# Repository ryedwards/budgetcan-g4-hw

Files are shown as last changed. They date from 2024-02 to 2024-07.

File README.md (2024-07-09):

# BudgetCAN G4

Hardware files for a simple CAN and LIN device built around an STM32 G4 MCU

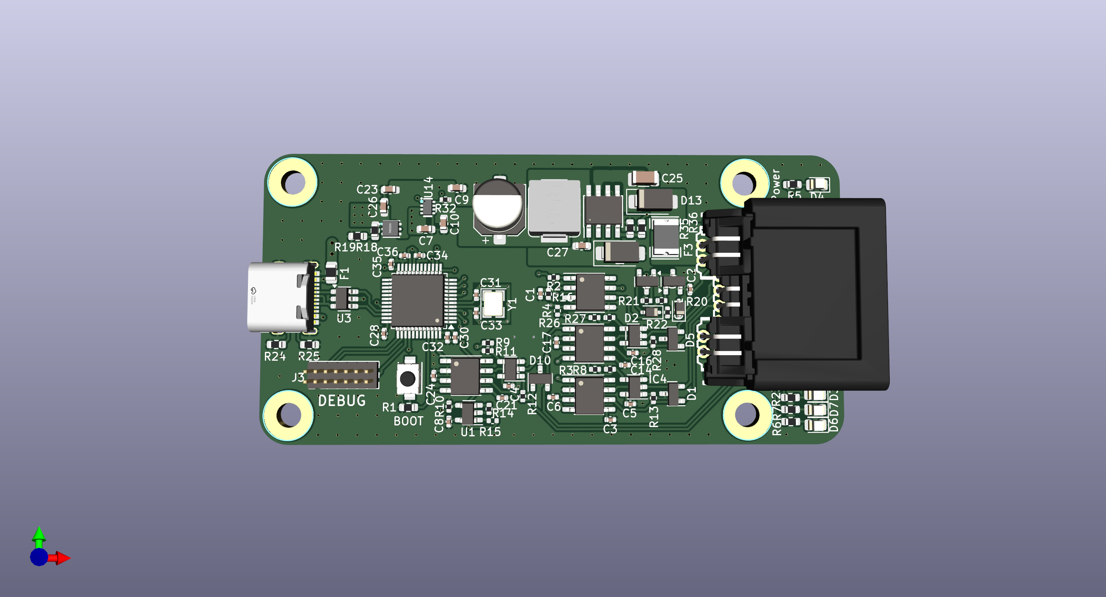
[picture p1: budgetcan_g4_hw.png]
budgetcan_g4_hardware


## Description

The BudgetCAN G4 Hardware is designed to implement the full CAN potential of the STM32G4 MCU.  The hardware has been designed with the following features:
* USB-C connector for robust connectivity to a host machine
* 3 CANFD channels each with SW selectable termination resistors
* 1 LIN channel with SW selectable master pull-up
* 12V power input provides power for LIN and a 3A 5V regulator
* Debug header pinout for STLINK v3 Mini 14-pin connector - the VCP pins are routed to a UART for debugging
* Onboard 8Mhz crystal provides high clock accuracy for CANFD
* 5V power MUX to ensure graceful handoff between USB and 12V power supplies
* 3x configurable LEDs for status indications
* Automotive grade Molex Mini50 connector
* 4 layer PCB
* BOM cost under $15USD

## File usage

* The HW was designed with KiCad8
* Part BOM included with the schematic is complete for JLCPCB parts

## Firmware
Firmware is available for this hardware in the budgetcan firmware repository.  This firmware is based on the gs_usb driver and currently is fully supported in Linux and will work in Windows using the same drivers that have been developed for gs_usb.
* https://github.com/ryedwards/budgetcan-fw

You can also use the included STM32CubeMX .ioc file to generate your own firmware.  

This hardware can also be used as a standalone device (gateway module, simulated ECU, etc) since it has a 12V input and can be used headless.

## Help

If you find any issues with the hardware please submit an issue into GitHub

## License

This project is licensed under the MIT License - see the LICENSE.md file for details

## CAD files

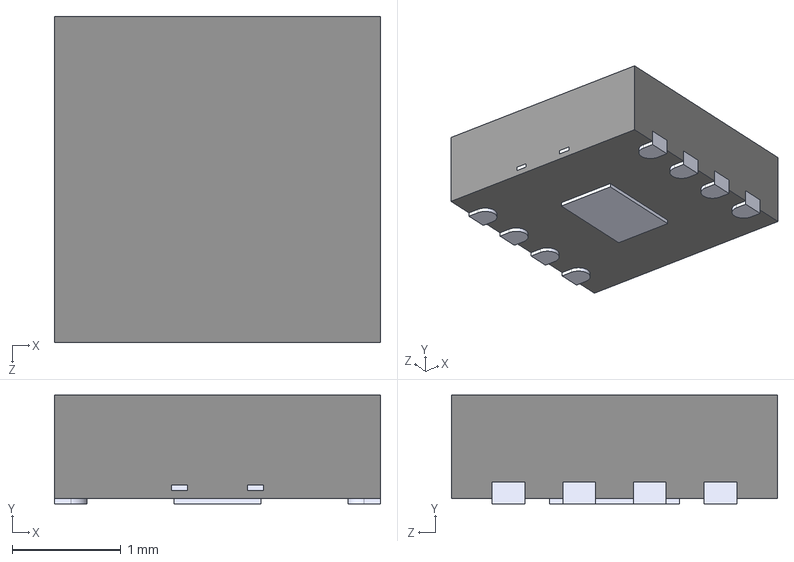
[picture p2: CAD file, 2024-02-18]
3dmodels/MF-TJA1021TK.STEP
3.00 x 1.00 x 3.00 mm

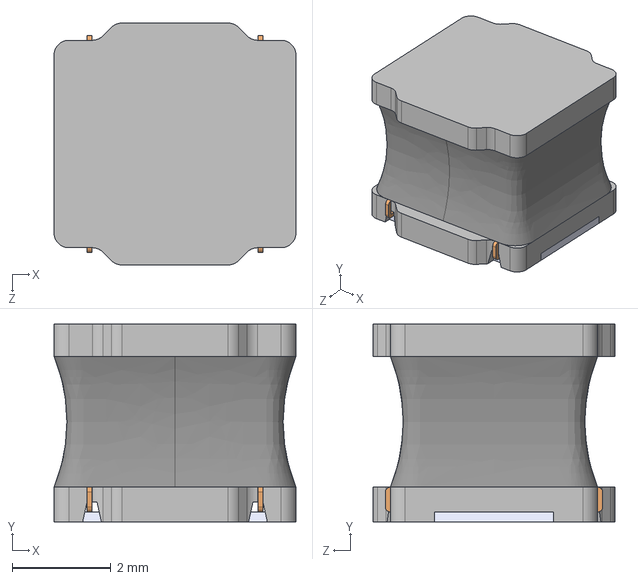
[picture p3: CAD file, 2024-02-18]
3dmodels/LQH5BPN3R3N38L.STEP
4.90 x 4.00 x 4.90 mm

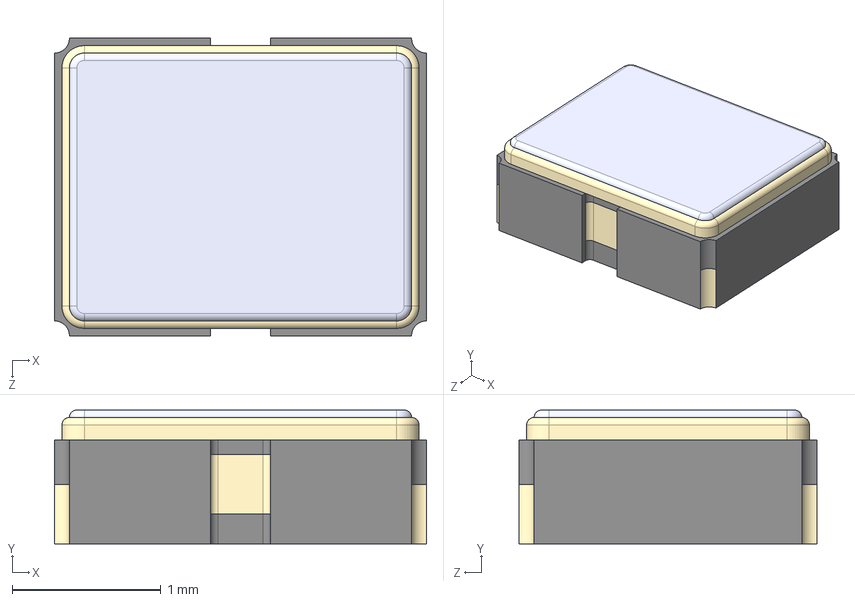
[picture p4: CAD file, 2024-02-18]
3dmodels/ECS-2520MVLC-080-BN-TR.STEP
2.50 x 0.9 x 2.00 mm

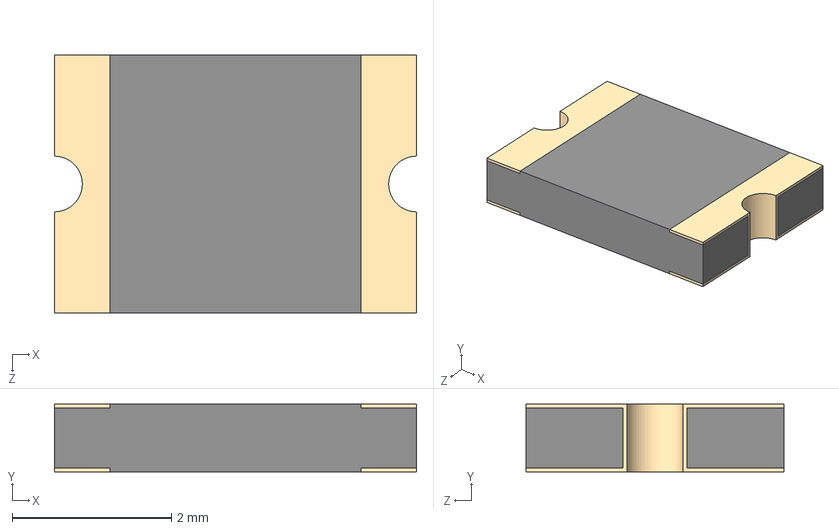
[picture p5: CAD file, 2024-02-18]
3dmodels/MF-MSMF050.STEP
4.55 x 0.85 x 3.24 mm

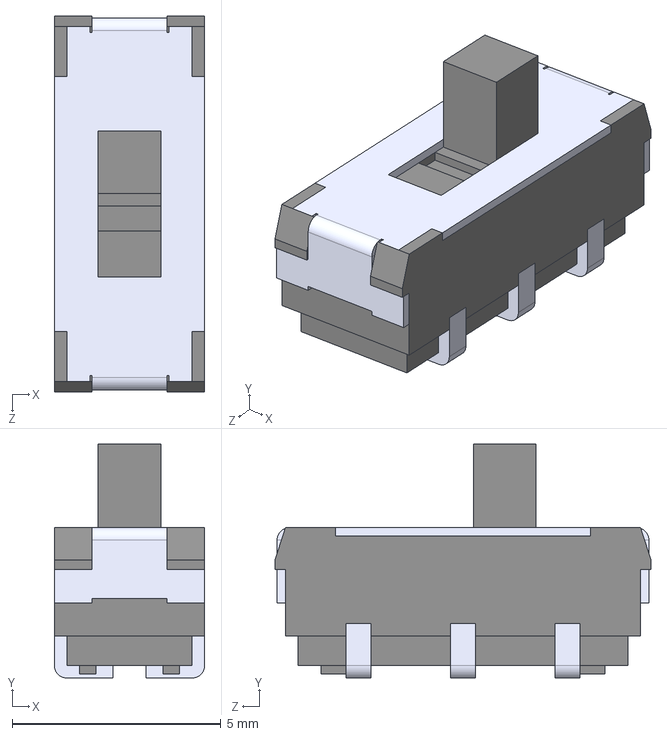
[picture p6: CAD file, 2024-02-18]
3dmodels/JS202011JCQN.STEP
3.60 x 5.60 x 9.00 mm

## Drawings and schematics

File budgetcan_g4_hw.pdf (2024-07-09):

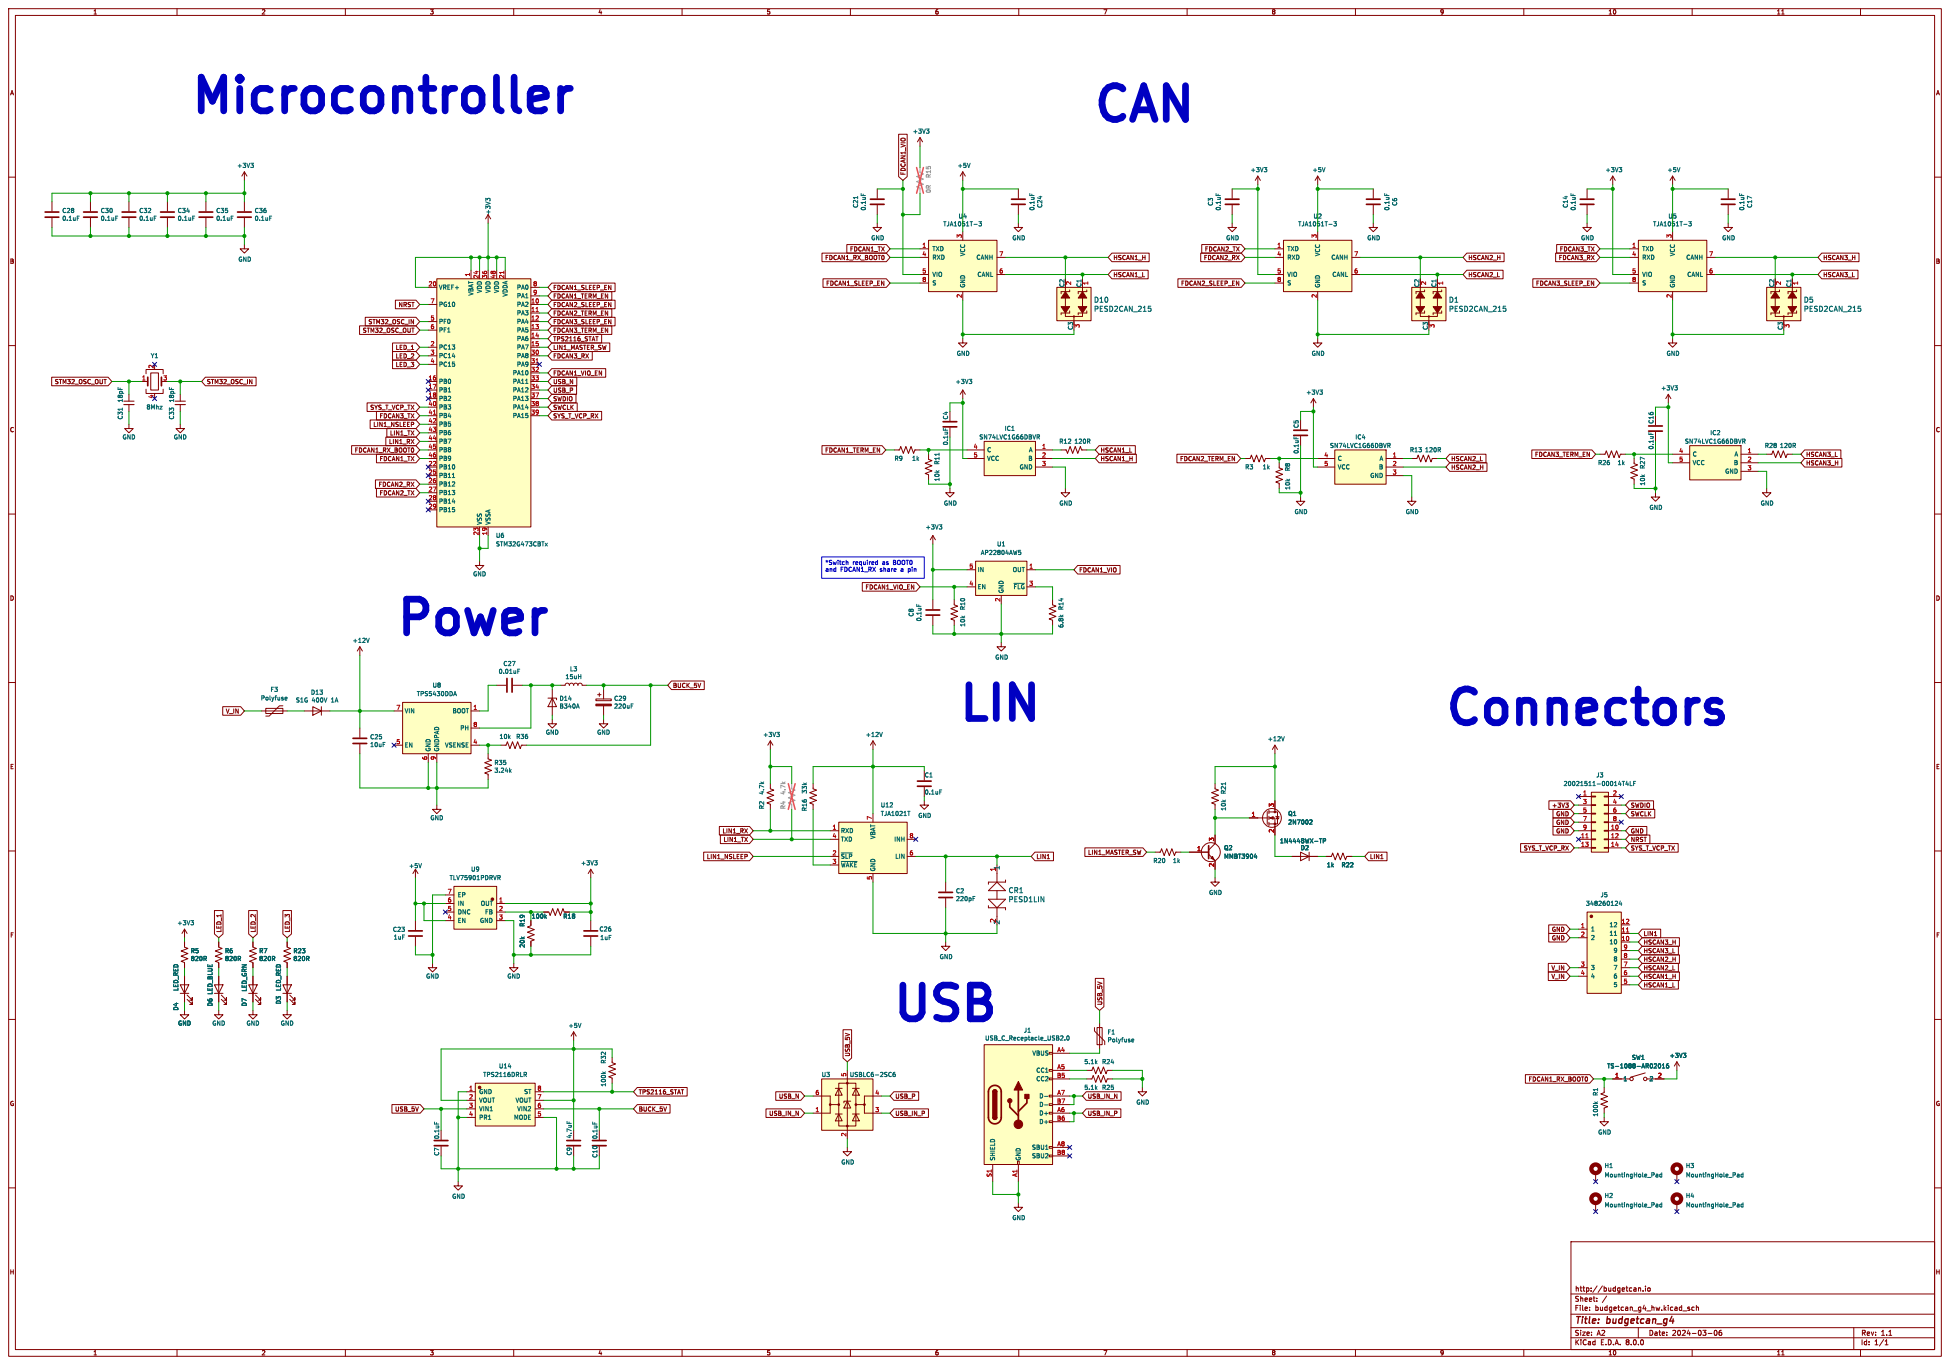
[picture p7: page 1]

3 RXD 4 VIO 5 CANL 6 CANH 7 S

1 PA2 10 PA3 11 PA4 12 PA5 13 PA6 14 PA7 15 PB0 16 PB1 17 PB2 18 VSSA 19 PC13 2 VREF+ 20 VDDA 21 PB10 22 VSS 23 VDD 24 PB11 25 PB12 26 PB13 27 PB14 28 PB15 29 PC14 3 PA8 30 PA9 31 PA10 32 PA11 33 PA12 34 VDD 36 PA13 37 PA14 38 PA15 39 PC15 4 PB3 40 PB4 41 PB5 42 PB6 43 PB7 44 PB8 45 PB9 46 VDD 48 PF0 5 PF1 6 PG10 7 PA0 8 PA1 9 U6STM32G473CBTx C10 0.1uF

File: budgetcan_g4_hw.kicad_sch Sheet: / http://budgetcan.io R10 10k

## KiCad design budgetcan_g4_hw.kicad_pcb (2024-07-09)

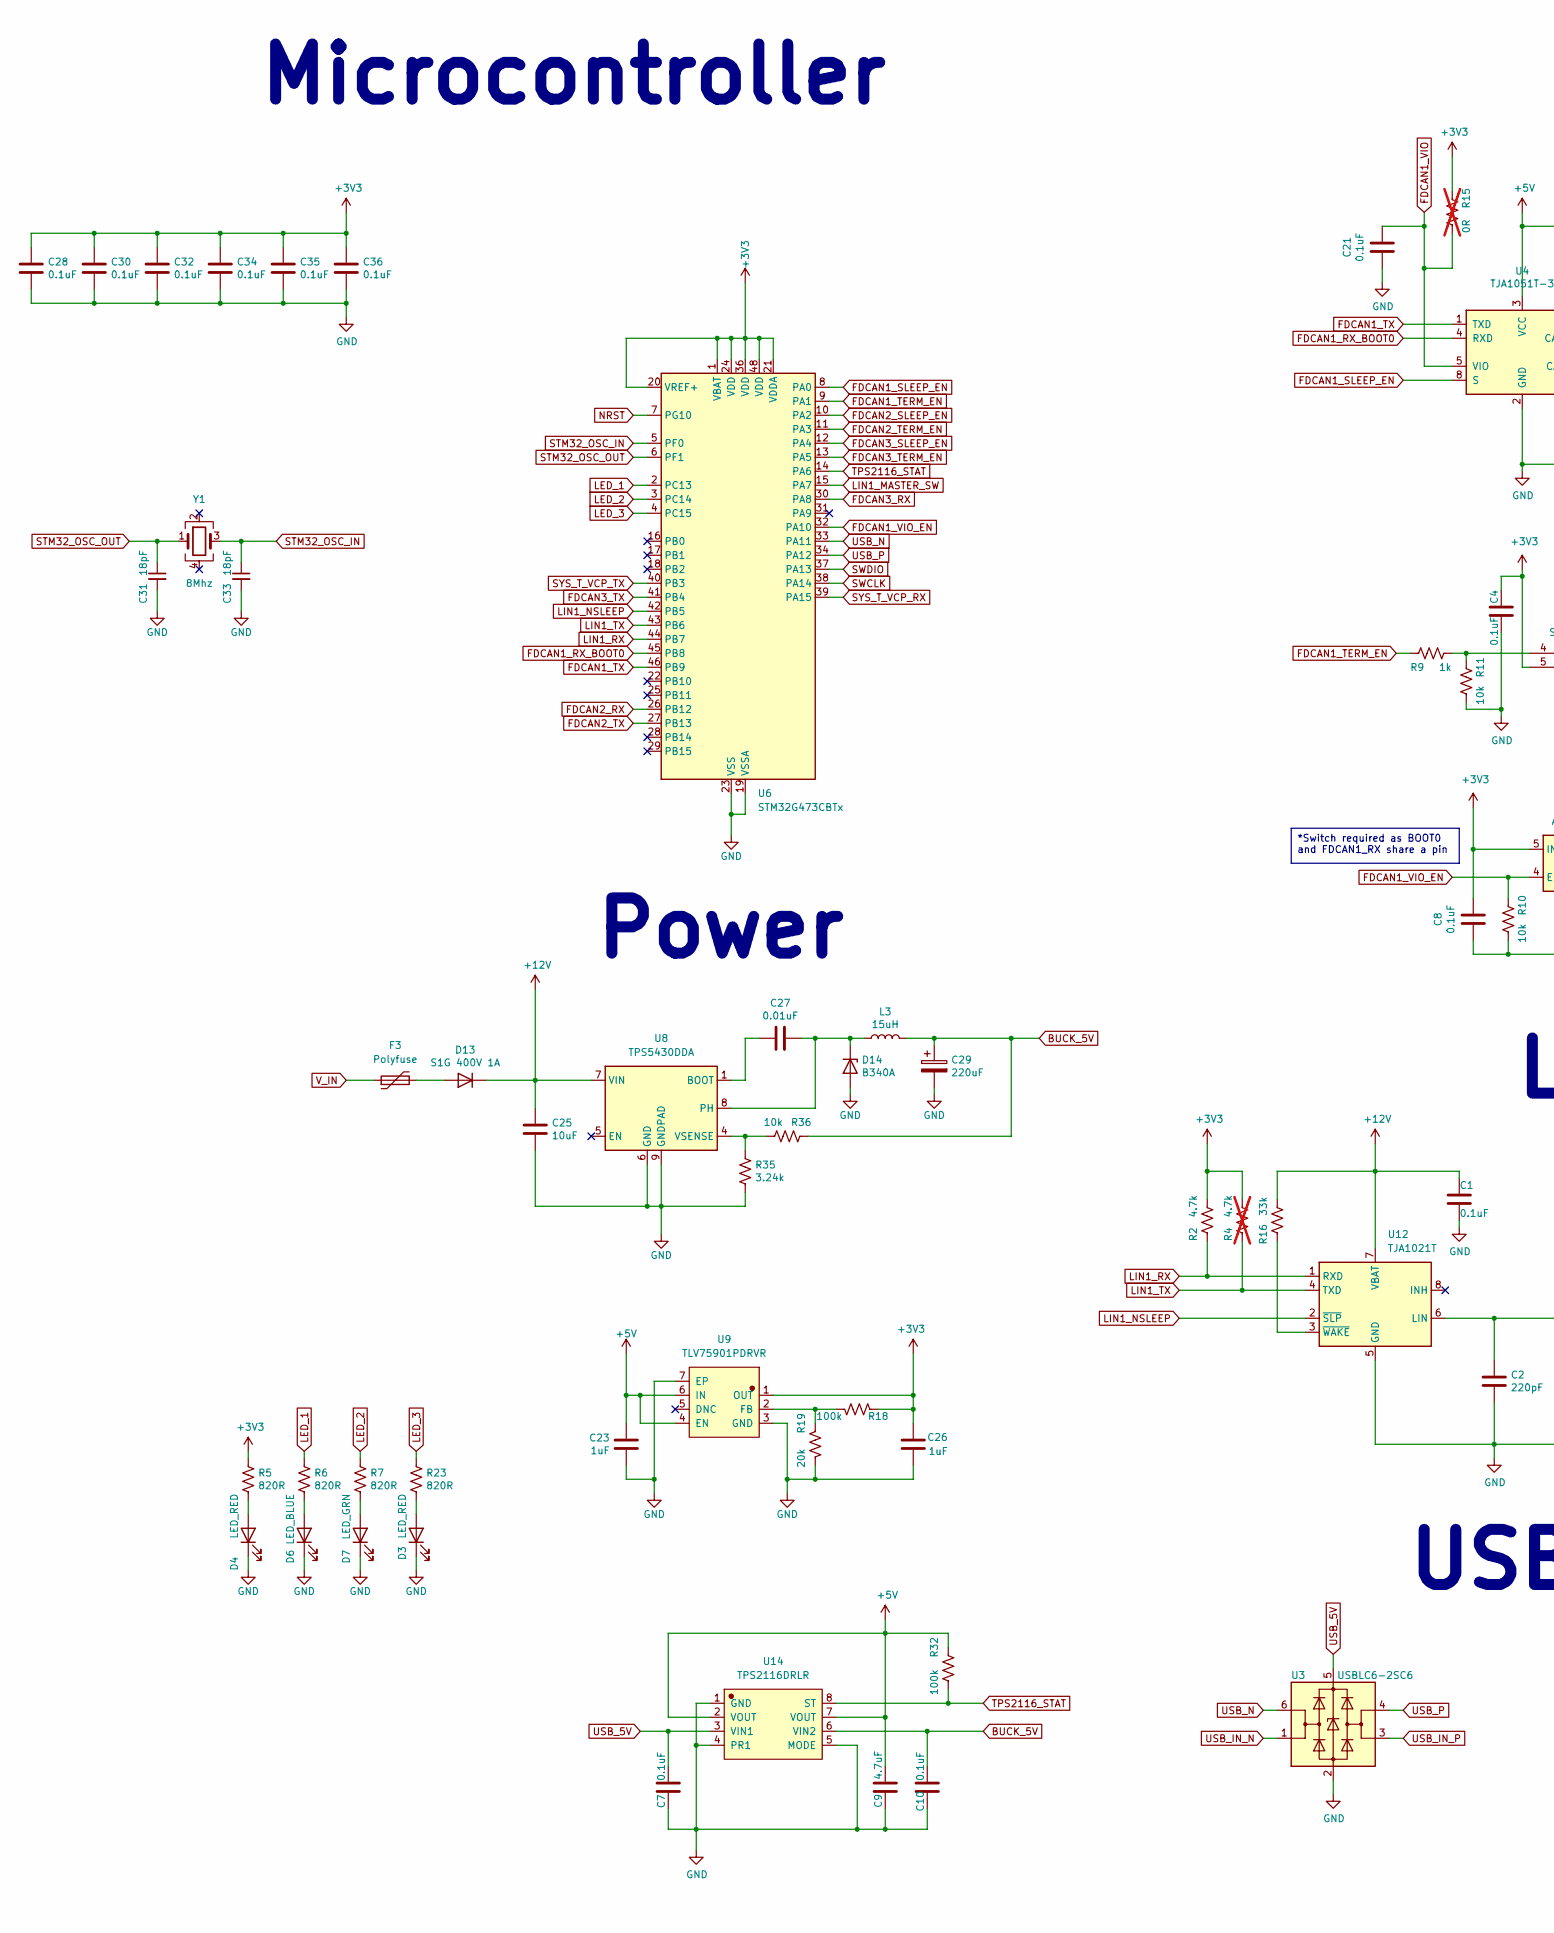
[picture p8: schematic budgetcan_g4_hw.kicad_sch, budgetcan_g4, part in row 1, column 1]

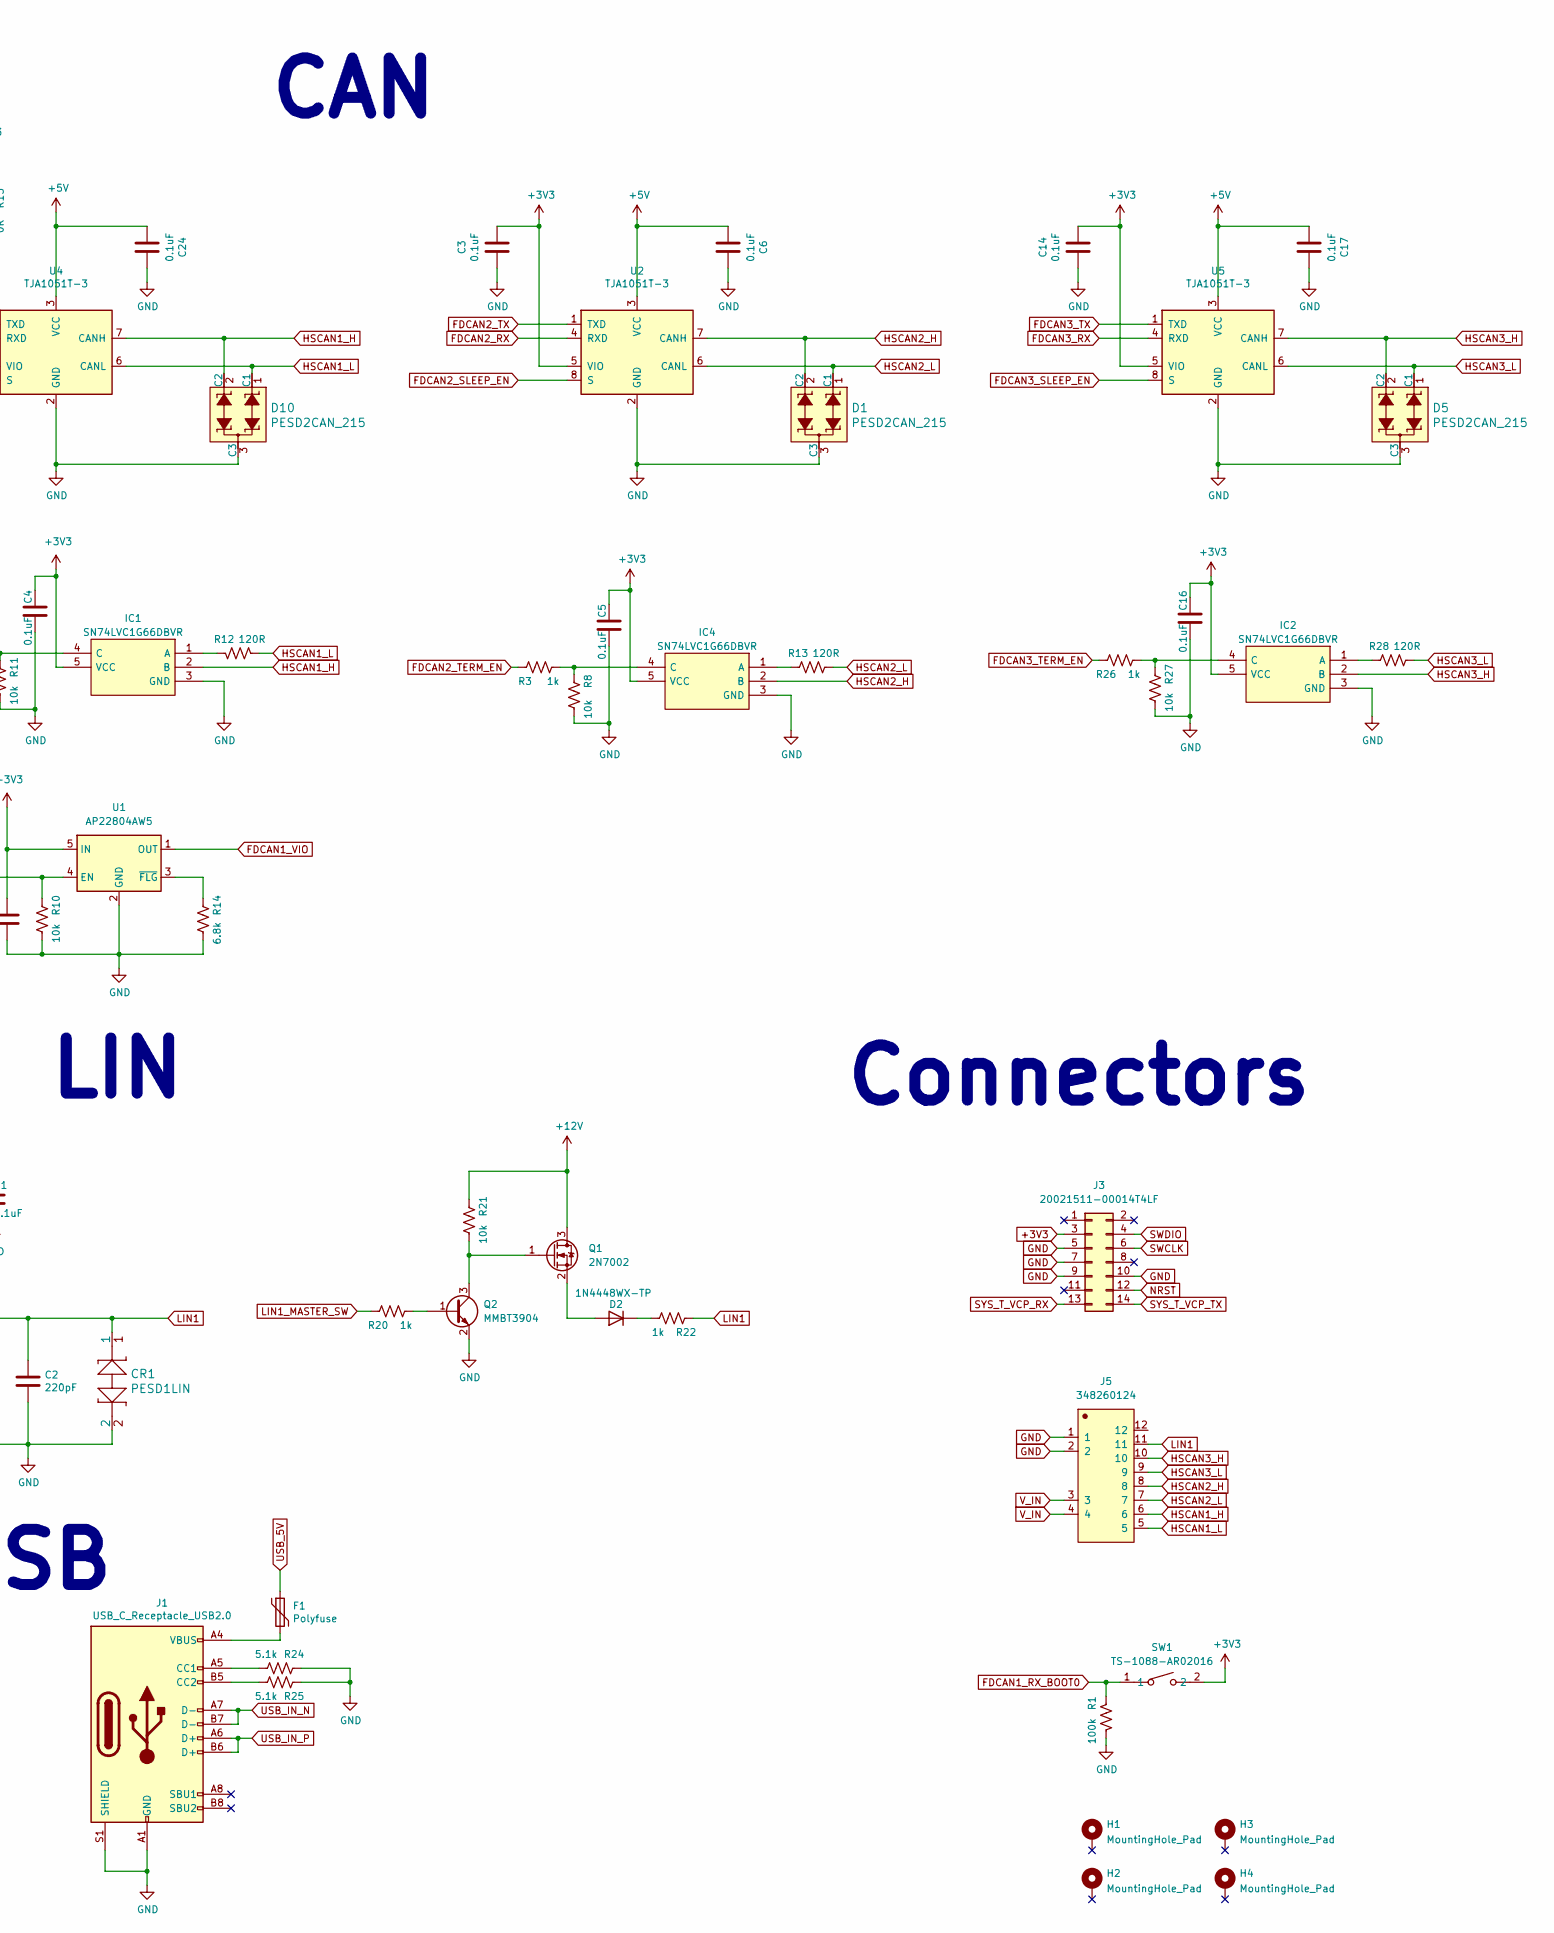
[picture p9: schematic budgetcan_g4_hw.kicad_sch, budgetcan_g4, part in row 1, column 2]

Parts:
C1, C3, C4, C5, C6, C8, C14, C16, C17, C21, C24: 0.1uF; C_0402_1005Metric; Manufacturer_Part_Number CC0603KRX7R8BB104; LCSC Part # C1525
C2: 220pF; C_0402_1005Metric; Manufacturer_Part_Number CC0603JRNPO9BN221; LCSC Part # C1530
C7, C10: 0.1uF; C_0603_1608Metric; Manufacturer_Part_Number CC0603KRX7R8BB104; LCSC Part # C14663
C9: 4.7uF; C_0603_1608Metric; LCSC Part # C19666
C23, C26: 1uF; C_0603_1608Metric; LCSC Part # C15849
C25: 10uF; C_1206_3216Metric; Manufacturer_Part_Number CL31B106KQHNFNE; LCSC Part # C13585
C27: 0.01uF; C_0603_1608Metric; LCSC Part # C57112
C28, C30, C32, C34, C35, C36: 0.1uF; C_0402_1005Metric; LCSC Part # C1525
C29: 220uF; CP_Elec_6.3x5.4; LCSC Part # C88676
C31, C33: 18pF; C_0402_1005Metric; LCSC Part # C1549
CR1: PESD1LIN; D_SOD-323; Manufacturer_Part_Number PESD1LIN,135; LCSC Part # C2831530
D1, D5, D10: PESD2CAN_215; SOT-23; MPN PESD2CAN,215; Digi-Key_PN 1727-3891-1-ND
D2: ‎1N4448WX-TP‎; D_SOD-323; Manufacturer_Part_Number ‎1N4448WX-TP‎; Digi-Key_PN 1N4448WXTPMSCT-ND
D3, D4: LED_RED; LED_0805_2012Metric; LCSC Part # C84256
D6: LED_BLUE; LED_0805_2012Metric; LCSC Part # C965817
D7: LED_GRN; LED_0805_2012Metric; LCSC Part # C2297
D13: S1G 400V 1A; D_SMA; Manufacturer_Part_Number S1G; LCSC Part # C95872
D14: B340A; D_SMA; LCSC Part # C3018525
F1: Polyfuse; Fuse_0805_2012Metric; Manufacturer_Part_Number 0ZCK0035FF2G; LCSC Part # C2833485
F3: Polyfuse; F1812; Manufacturer_Part_Number 0ZCG0200AF2B; Digi-Key_PN 507-2074-1-ND
H1, H2, H3, H4: MountingHole_Pad; MountingHole_3.2mm_M3_Pad_TopBottom
IC1, IC2, IC4: SN74LVC1G66DBVR; SOT-23-5; Manufacturer_Part_Number SN74LVC1G66DBVR; LCSC Part # C5375974
J1: USB_C_Receptacle_USB2.0; USB_C_Receptacle_Palconn_UTC16-G; Manufacturer_Part_Number USB4085-GF-A; Digi-Key_PN 2073-USB4085-GF-ACT-ND
J3: 20021511-00014T4LF; PinHeader_2x07_P1.27mm_Vertical; Mouser Part Number 200-FTSH10701LDK
J5: 348260124; CONN-TH_348260124; LCSC Part # C587298
L3: 15uH; L_Bourns_SRP7028A_7.3x6.6mm; LCSC Part # C5189959
Q1: 2N7002; SOT-23; LCSC Part # C8545
Q2: MMBT3904; SOT-23; LCSC Part # C20526
R1: 100k; R_0603_1608Metric; Manufacturer_Part_Number RC0603FR-07100KL; LCSC Part # C25803
R2: 4.7k; R_0402_1005Metric; Manufacturer_Part_Number RC0603JR-074K7L; LCSC Part # C25900
R3, R9, R20, R22, R26: 1k; R_0402_1005Metric; Manufacturer_Part_Number RC0603FR-071KL; LCSC Part # C11702
R4: 4.7k; R_0402_1005Metric; LCSC Part # C25900; not fitted
R5, R6, R7, R23: 820R; R_0603_1608Metric; Manufacturer_Part_Number RC0603FR-071KL; LCSC Part # C23253
R8, R10, R11, R21, R27: 10k; R_0402_1005Metric; Manufacturer_Part_Number RC0603FR-0710KL; LCSC Part # C25744
R12, R13, R28: 120R; R_0402_1005Metric; Manufacturer_Part_Number RC0603FR-07120RL; LCSC Part # C25079
R14: 6.8k; R_0402_1005Metric; Manufacturer_Part_Number RC0603FR-0710KL; LCSC Part # C25917
R15: 0R; R_0402_1005Metric; LCSC Part # C17168; not fitted
R16: 33k; R_0402_1005Metric; Manufacturer_Part_Number RC0603FR-0733K2L; LCSC Part # C25779
R18: 100k; R_0603_1608Metric; Manufacturer_Part_Number RC0603FR-0710KL; LCSC Part # C25803
R19: 20k; R_0603_1608Metric; Manufacturer_Part_Number RC0603FR-0710KL; LCSC Part # C4184
R24, R25: 5.1k; R_0603_1608Metric; Manufacturer_Part_Number RC0603JR-075K1L; LCSC Part # C23186
R32: 100k; R_0402_1005Metric; Manufacturer_Part_Number RC0603FR-0710KL; LCSC Part # C25741
R35: 3.24k; R_0603_1608Metric; LCSC Part # C22994
R36: 10k; R_0603_1608Metric; LCSC Part # C25804
SW1: TS-1088-AR02016; SW-SMD_L3.9-W3.0-P4.45; LCSC Part # C720477
U1: AP22804AW5; SOT-23-5; LCSC Part # C89855
U2, U4, U5: TJA1051T-3; SOIC-8_3.9x4.9mm_P1.27mm; LCSC Part # C38695
U3: USBLC6-2SC6; SOT-23-6; Manufacturer_Part_Number USBLC6-2SC6; LCSC Part # C2687116
U6: STM32G473CBTx; LQFP-48_7x7mm_P0.5mm; LCSC Part # C730111
U8: TPS5430DDA; TI_SO-PowerPAD-8_ThermalVias; LCSC Part # C9864
U9: TLV75901PDRVR; WSON-6_L2.0-W2.0-P0.65-TL-EP; LCSC Part # C544759
U12: TJA1021T; SOIC-8_3.9x4.9mm_P1.27mm; LCSC Part # C128810
U14: TPS2116DRLR; SOT-583-8_L2.1-W1.6-P0.50-LS1.6-BL; LCSC Part # C3235557
Y1: 8Mhz; Crystal_SMD_3225-4Pin_3.2x2.5mm; LCSC Part # C963531

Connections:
+3V3: C3.1, C4.1, C5.1, C8.1, C14.1, C16.1, C26.1, C28.1, C30.1, C32.1, C34.1, C35.1, C36.1, IC1.5 (VCC), IC2.5 (VCC), IC4.5 (VCC), J3.3, R2.2, R4.2, R5.2, R15.1, R18.1, SW1.2, U1.5 (IN), U2.5 (VIO), U5.5 (VIO), U6.1 (VBAT), U6.20 (VREF+), U6.21 (VDDA), U6.24 (VDD), U6.36 (VDD), U6.48 (VDD), U9.1 (OUT)
+5V: C6.2, C9.1, C17.2, C23.1, C24.2, R32.1, U2.3 (VCC), U4.3 (VCC), U5.3 (VCC), U9.4 (EN), U9.6 (IN), U14.2 (VOUT), U14.7 (VOUT)
+12V: C1.1, C25.1, D13.1 (K), Q1.3 (D), R16.2, R21.1, U8.7 (VIN), U12.7 (VBAT)
BUCK_5V: C10.1, C29.1, L3.2, R36.2, U14.6 (VIN2)
FDCAN1_RX_BOOT0: R1.1, SW1.1, U4.4 (RXD), U6.45 (PB8)
FDCAN1_SLEEP_EN: U4.8 (S), U6.8 (PA0)
FDCAN1_TERM_EN: R9.1, U6.9 (PA1)
FDCAN1_TX: U4.1 (TXD), U6.46 (PB9)
FDCAN1_VIO: C21.1, R15.2, U1.1 (OUT), U4.5 (VIO)
FDCAN1_VIO_EN: R10.1, U1.4 (EN), U6.32 (PA10)
FDCAN2_RX: U2.4 (RXD), U6.26 (PB12)
FDCAN2_SLEEP_EN: U2.8 (S), U6.10 (PA2)
FDCAN2_TERM_EN: R3.1, U6.11 (PA3)
FDCAN2_TX: U2.1 (TXD), U6.27 (PB13)
FDCAN3_RX: U5.4 (RXD), U6.30 (PA8)
FDCAN3_SLEEP_EN: U5.8 (S), U6.12 (PA4)
FDCAN3_TERM_EN: R26.1, U6.13 (PA5)
FDCAN3_TX: U5.1 (TXD), U6.41 (PB4)
GND: C1.2, C2.2, C3.2, C4.2, C5.2, C6.1, C7.2, C8.2, C9.2, C10.2, C14.2, C16.2, C17.1, C21.2, C23.2, C24.1, C25.2, C26.2, C28.2, C29.2, C30.2, C31.2, C32.2, C33.2, C34.2, C35.2, C36.2, CR1.2, D1.3 (C3), D3.1 (K), D4.1 (K), D5.3 (C3), D6.1 (K), D7.1 (K), D10.3 (C3), D14.2 (A), IC1.3 (GND), IC2.3 (GND), IC4.3 (GND), J1.A1 (GND), J1.A12 (GND), J1.B1 (GND), J1.B12 (GND), J1.S1 (SHIELD), J3.5, J3.7, J3.9, J3.10, J5.1, J5.2, Q2.2 (E), R1.2, R8.2, R10.2, R11.2, R14.2, R19.2, R24.1, R25.1, R27.2, R35.2, U1.2 (GND), U2.2 (GND), U3.2 (GND), U4.2 (GND), U5.2 (GND), U6.19 (VSSA), U6.23 (VSS), U6.35 (VSS), U6.47 (VSS), U8.6 (GND), U8.9 (GNDPAD), U9.3 (GND), U9.7 (EP), U12.5 (GND), U14.1 (GND), U14.4 (PR1), U14.5 (MODE)
HSCAN1_H: D10.2 (C2), IC1.2 (B), J5.6, U4.7 (CANH)
HSCAN1_L: D10.1 (C1), J5.5, R12.2, U4.6 (CANL)
HSCAN2_H: D1.2 (C2), IC4.2 (B), J5.8, U2.7 (CANH)
HSCAN2_L: D1.1 (C1), J5.7, R13.2, U2.6 (CANL)
HSCAN3_H: D5.2 (C2), IC2.2 (B), J5.10, U5.7 (CANH)
HSCAN3_L: D5.1 (C1), J5.9, R28.2, U5.6 (CANL)
LED_1: R6.2, U6.2 (PC13)
LED_2: R7.2, U6.3 (PC14)
LED_3: R23.2, U6.4 (PC15)
LIN1: C2.1, CR1.1, J5.11, R22.1, U12.6 (LIN)
LIN1_MASTER_SW: R20.1, U6.15 (PA7)
LIN1_NSLEEP: U6.42 (PB5), U12.2 (~SLP)
LIN1_RX: R2.1, U6.44 (PB7), U12.1 (RXD)
LIN1_TX: R4.1, U6.43 (PB6), U12.4 (TXD)
NRST: J3.12, U6.7 (PG10)
unnamed: D2.2 (A), Q1.2 (S)
unnamed: D2.1 (K), R22.2
unnamed: D3.2 (A), R23.1
unnamed: D4.2 (A), R5.1
unnamed: D6.2 (A), R6.1
unnamed: D7.2 (A), R7.1
unnamed: D13.2 (A), F3.2
unnamed: C27.1, D14.1 (K), L3.1, U8.8 (PH)
unnamed: F1.2, J1.A4 (VBUS), J1.A9 (VBUS), J1.B4 (VBUS), J1.B9 (VBUS)
unnamed: IC1.1 (A), R12.1
unnamed: IC1.4 (C), R9.2, R11.1
unnamed: IC2.1 (A), R28.1
unnamed: IC2.4 (C), R26.2, R27.1
unnamed: IC4.1 (A), R13.1
unnamed: IC4.4 (C), R3.2, R8.1
unnamed: J1.A5 (CC1), R24.2
unnamed: J1.B5 (CC2), R25.2
unnamed: Q1.1 (G), Q2.3 (C), R21.2
unnamed: Q2.1 (B), R20.2
unnamed: R14.1, U1.3 (~FLG)
unnamed: C27.2, U8.1 (BOOT)
unnamed: R35.1, R36.1, U8.4 (VSENSE)
unnamed: R18.2, R19.1, U9.2 (FB)
unnamed: R16.1, U12.3 (~WAKE)
STM32_OSC_IN: C33.1, U6.5 (PF0), Y1.3
STM32_OSC_OUT: C31.1, U6.6 (PF1), Y1.1
SWCLK: J3.6, U6.38 (PA14)
SWDIO: J3.4, U6.37 (PA13)
SYS_T_VCP_RX: J3.13, U6.39 (PA15)
SYS_T_VCP_TX: J3.14, U6.40 (PB3)
TPS2116_STAT: R32.2, U6.14 (PA6), U14.8 (ST)
USB_5V: C7.1, F1.1, U3.5 (VBUS), U14.3 (VIN1)
USB_IN_N: J1.A7 (D-), J1.B7 (D-), U3.1 (I/O1)
USB_IN_P: J1.A6 (D+), J1.B6 (D+), U3.3 (I/O2)
USB_N: U3.6 (I/O1), U6.33 (PA11)
USB_P: U3.4 (I/O2), U6.34 (PA12)
V_IN: F3.1, J5.3, J5.4

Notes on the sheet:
*Switch required as BOOT0 and FDCAN1_RX share a pin
LIN
Microcontroller
CAN
Power
USB
Connectors

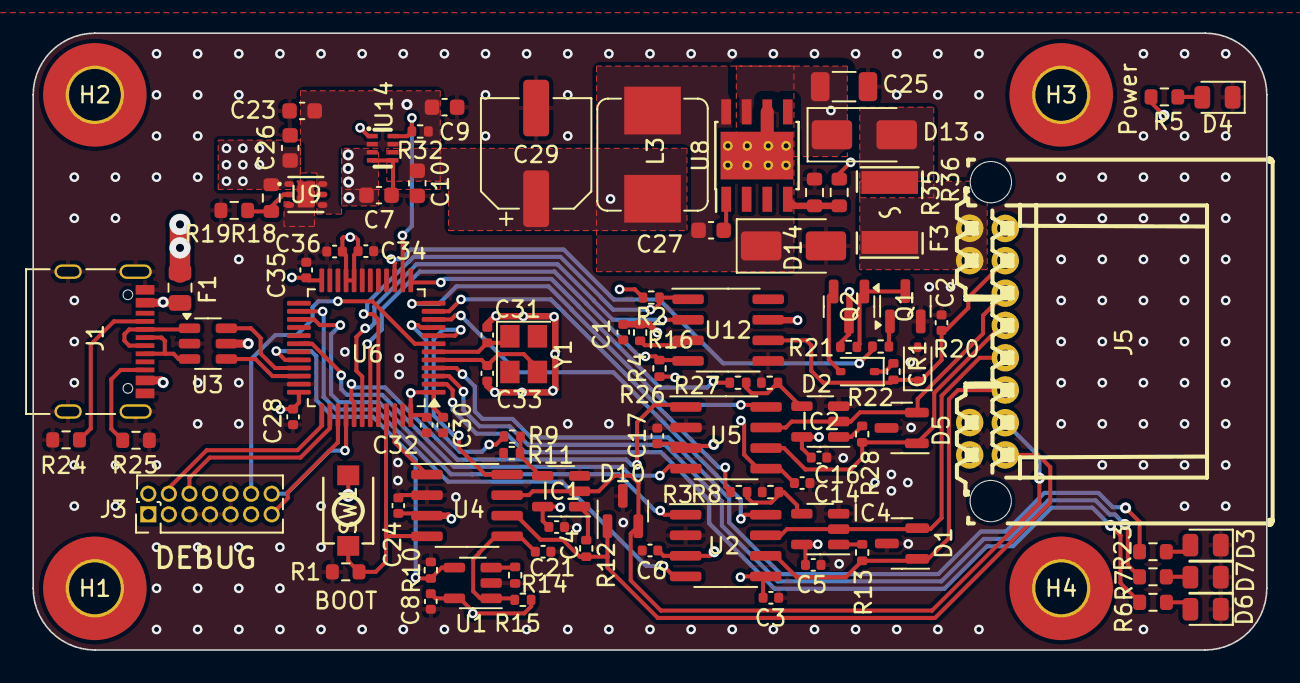
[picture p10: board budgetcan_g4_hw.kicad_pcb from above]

Board: 4 copper layers, 76.2 x 38.1 mm, 96 parts (0 on the bottom side), 71 nets.

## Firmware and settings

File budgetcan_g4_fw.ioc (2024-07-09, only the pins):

Mcu.UserName=STM32G473CBTx
PA0.GPIO_Label=FDCAN1_SLEEP_EN
PA0.Signal=GPIO_Output
PA1.GPIO_Label=FDCAN1_TERM_EN
PA1.Signal=GPIO_Output
PA10.GPIO_Label=FDCAN1_VIO_EN
PA10.Signal=GPIO_Output
PA11.Signal=USB_DM
PA12.Signal=USB_DP
PA13.Signal=SYS_JTMS-SWDIO
PA14.Signal=SYS_JTCK-SWCLK
PA15.Signal=USART2_RX
PA2.GPIO_Label=FDCAN2_SLEEP_EN
PA2.Signal=GPIO_Output
PA3.GPIO_Label=FDCAN2_TERM_EN
PA3.Signal=GPIO_Output
PA4.GPIO_Label=FDCAN3_SLEEP_EN
PA4.Signal=GPIO_Output
PA5.GPIO_Label=FDCAN3_TERM_EN
PA5.Signal=GPIO_Output
PA6.GPIO_Label=TPS2116_STAT
PA6.Signal=GPIO_Input
PA7.GPIO_Label=LIN1_MASTER_EN
PA7.Signal=GPIO_Output
PA8.Signal=FDCAN3_RX
PB12.Signal=FDCAN2_RX
PB13.Signal=FDCAN2_TX
PB3.Signal=USART2_TX
PB4.Signal=FDCAN3_TX
PB5.GPIO_Label=LIN1_nSLEEP
PB5.Signal=GPIO_Output
PB6.Signal=USART1_TX
PB7.Signal=USART1_RX
PB8-BOOT0.Signal=FDCAN1_RX
PB9.Signal=FDCAN1_TX
PC13.GPIO_Label=LED1
PC13.Signal=GPIO_Output
PC14-OSC32_IN.GPIO_Label=LED2
PC14-OSC32_IN.Signal=GPIO_Output
PC15-OSC32_OUT.GPIO_Label=LED3
PC15-OSC32_OUT.Signal=GPIO_Output
PF0-OSC_IN.Signal=RCC_OSC_IN
PF1-OSC_OUT.Signal=RCC_OSC_OUT

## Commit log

2024-02-19 Fix the LCSC part number for the CAN termination switch
    [budgetcan_g4_hw.kicad_sch]
2024-03-04 Fix incorrect connection of the 3.3V regulator feedback resistors
    [budgetcan_g4_hw.kicad_pcb, budgetcan_g4_hw.kicad_sch]
2024-03-07 Update to KiCad 8 and fix USB pinouts
    [budgetcan_g4_hw.kicad_pcb, budgetcan_g4_hw.kicad_sch]
2024-07-09 Changes to fix issues found with prototype
    - Fixed the power feed for FDCAN1 from switching the 5V feed (VCC) to the 3.3V feed (VIO)
    - Changed the XTAL to 8Mhz
    - Added a SW controlled master switch for LIN
    - Changed the boot selector to a button switch
    [budgetcan_g4_hw.kicad_pcb, budgetcan_g4_hw.kicad_sch]
